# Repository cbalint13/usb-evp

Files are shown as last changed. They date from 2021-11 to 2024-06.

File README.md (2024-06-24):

# usb-evp
**USB Event Packet** protocol (LoRA) Stick

Original project dating back @ 2018 [CircuitMaker USB-EVP-LoRa](https://workspace.circuitmaker.com/Projects/Details/Cristian-Balint/USB-EVP-LoRa)

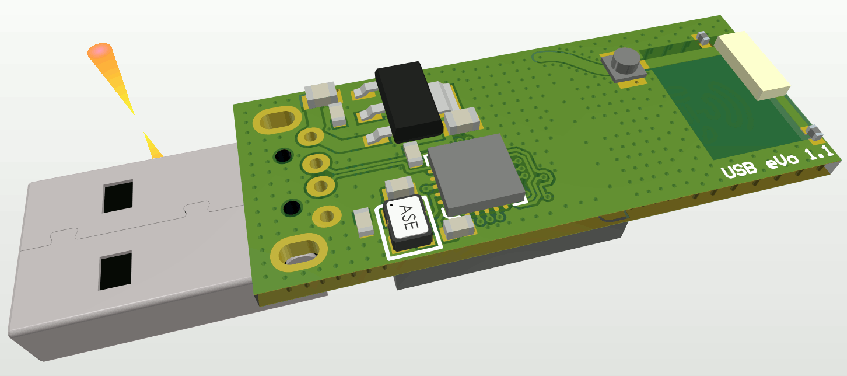
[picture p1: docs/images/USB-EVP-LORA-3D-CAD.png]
OVERVIEW-3D-CAD


## Description

USB stick for **Event Packet** (over LoRa) with integrated antenna on ISM 868/915 bands.

Exposes a generic USB HID interface by MCP2210 directly enabling OS & driver agnostic access from userland.

It have a minimal BOM (bill of materials).
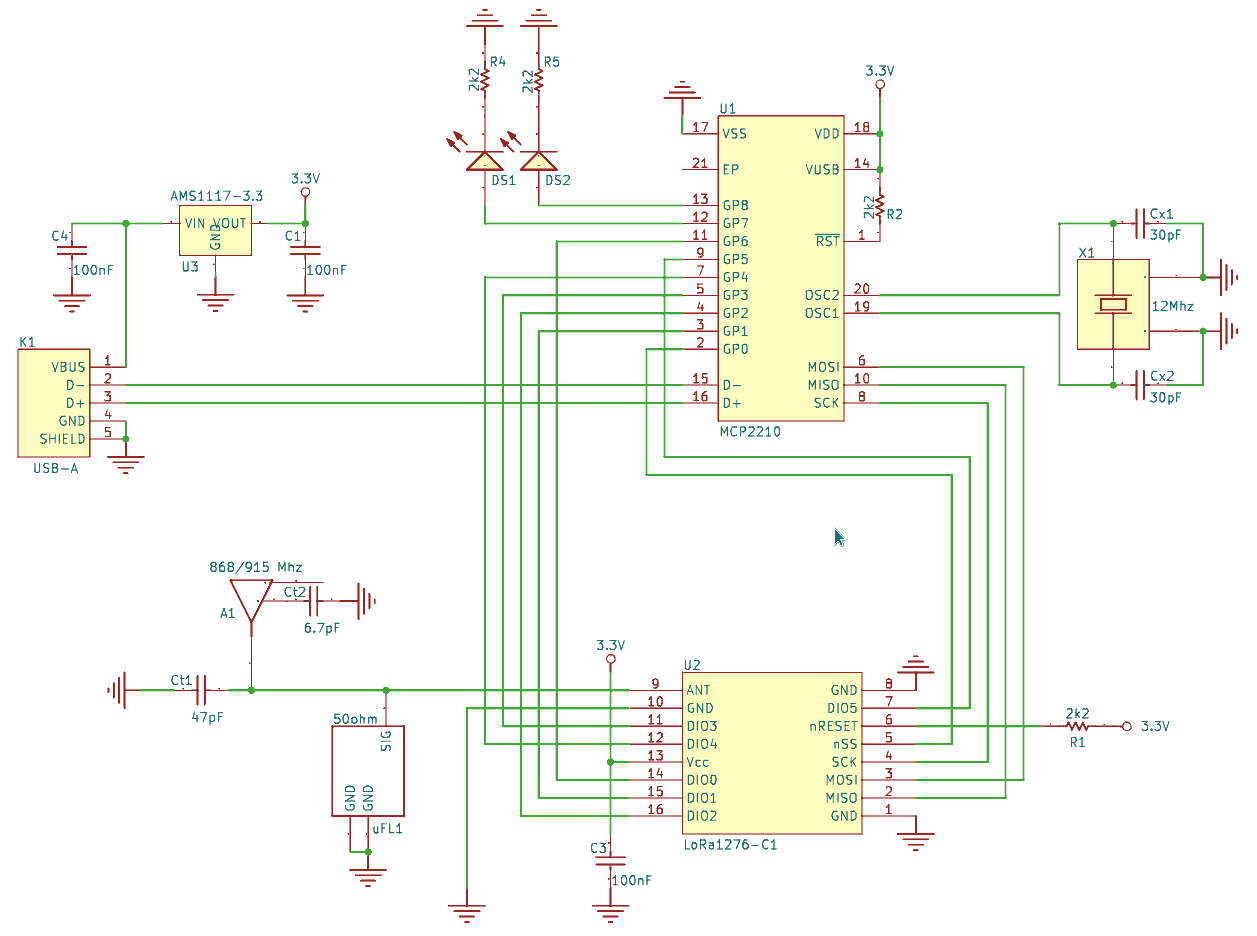
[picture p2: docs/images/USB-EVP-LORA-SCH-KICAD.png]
OVERVIEW-3D-SCHD


## Specs:

* **Smallest LoRa stick** on the market by 1.6 x 4 cm
* Uses FCC and CE **certified** 100mW NiceRF module
* Own **ceramic micro-antenna** (VNA proved RF) for ISM band
* **OS agnostic**, opensource USB stack for windows, linux, android etc
* **C / C++** frontend with various examples
* May support **LPWAN networking** (IPv6 over 802.15.4 mac layer), with third party kernel module

Can be used in any USB port realying packets over the air.

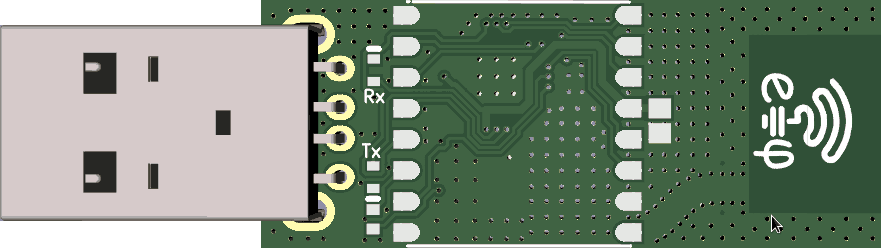
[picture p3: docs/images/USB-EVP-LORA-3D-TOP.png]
OVERVIEW-3D-TOP

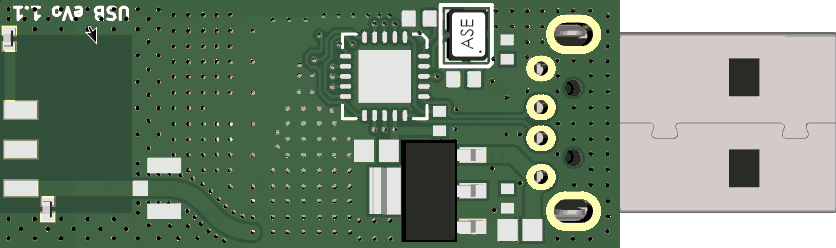
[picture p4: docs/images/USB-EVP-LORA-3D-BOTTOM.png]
OVERVIEW-3D-BOTTOM


## EU ISM band usage 
* [LoRa 868Mhz bands diagram](docs/legal)

## Design files
* See the [design files](hardware) available for Altium ®, CircuitMaker ®, KiCAD and Gerber format.
* Check [schematic](hardware/USB-eVo_v1.1.pdf) available as quick readable format.
* There is also an CircuitMaker ® [online version](https://circuitmaker.com/Projects/Details/Cristian-Balint/USB-EVP-LoRa) available.

## Software support
* See [software](software) section for configuration and support.

    ```
    $ ./bin/lora-receive /dev/hidraw4 
    LoRa RX count #1 frame length = 14 rssi = -61 dB snr = 8 dB
    0x00000000 20 6C 6F 72 61 20 6D 65  73 73 61 67 65 00 |  A lora message.
    ```

## Board images
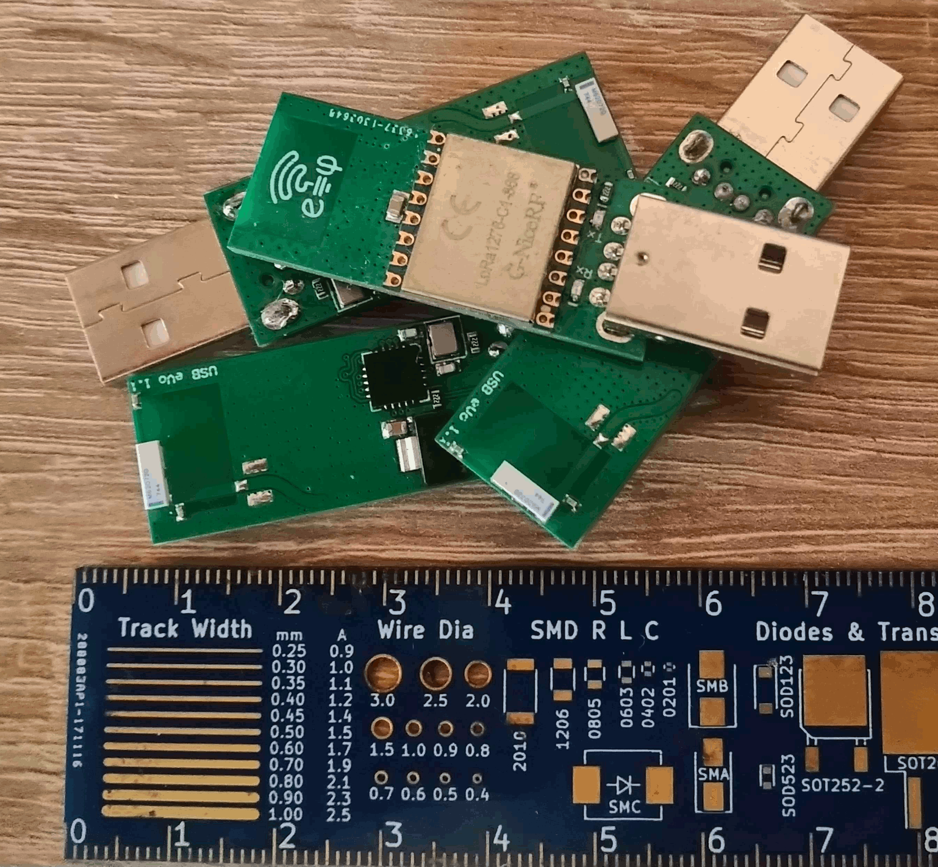
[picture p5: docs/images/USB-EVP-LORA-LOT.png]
OVERVIEW-TOP


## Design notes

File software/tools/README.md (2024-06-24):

# USB stick library stack

You can compile all tools using the provided ```make.sh```.

---

## Applications

 * Use ```scan.sh``` to fetch the exact device path:

    ```
    $ ./scan.sh
    /dev/hidraw0 Lite-On Technology Corp. Lenovo Low Profile USB Keyboard
    /dev/hidraw1 Lite-On Technology Corp. Lenovo Low Profile USB Keyboard
    /dev/hidraw2 ITE Tech. Inc. ITE Device
    /dev/hidraw3 Designer Mouse
    /dev/hidraw4 EventPacket [eVo] USB Stick v1.2
    ```

 * Chipset (SX127x) revision check:

    ```
    $ ./bin/check-version /dev/hidraw4
    SX127X chip version: 0x12
    ```

 * Random number generator based on wideband RSSI measurement:

    ```
    $ ./bin/sx127x-random /dev/hidraw4
    Found SX127X chip version: 12
    253
    186
    97
    216
    157
    ...
    ```

 * LoRa receive example:

    ```
    $ ./bin/lora-receive /dev/hidraw4 
    LoRa RX count #1 frame length = 14 rssi = -61 dB snr = 8 dB
    0x00000000 20 6C 6F 72 61 20 6D 65  73 73 61 67 65 00 |  A lora message.
    ```

 * LoRa sending example:

    ```
    $ ./bin/lora-send /dev/hidraw4
    LoRa sent message
    ```

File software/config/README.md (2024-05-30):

# LoRa USB stick initial configuration

* Please check and compile the [mcp2210-tool](https://github.com/lkundrak/mcp2210)
* Use the ```evp-lora-stick-hwcfg.sh``` script to initialize the USB stick NVRAM settings

---

The ```dmesg``` output summary:

```
$ dmesg
...
[296427.566309] usb 1-6: new full-speed USB device number 7 using xhci_hcd
[296427.695951] usb 1-6: New USB device found, idVendor=04d8, idProduct=00de, bcdDevice= 0.02
[296427.695968] usb 1-6: New USB device strings: Mfr=1, Product=2, SerialNumber=3
[296427.695975] usb 1-6: Product: [eVo] USB Stick v1.2
[296427.695981] usb 1-6: Manufacturer: EventPacket
[296427.695986] usb 1-6: SerialNumber: 0000818649
[296427.700092] hid-generic 0003:04D8:00DE.0005: hiddev97,hidraw4: USB HID v1.11 Device [EventPacket [eVo] USB Stick v1.2] on usb-0000:00:14.0-6/input0
...
```

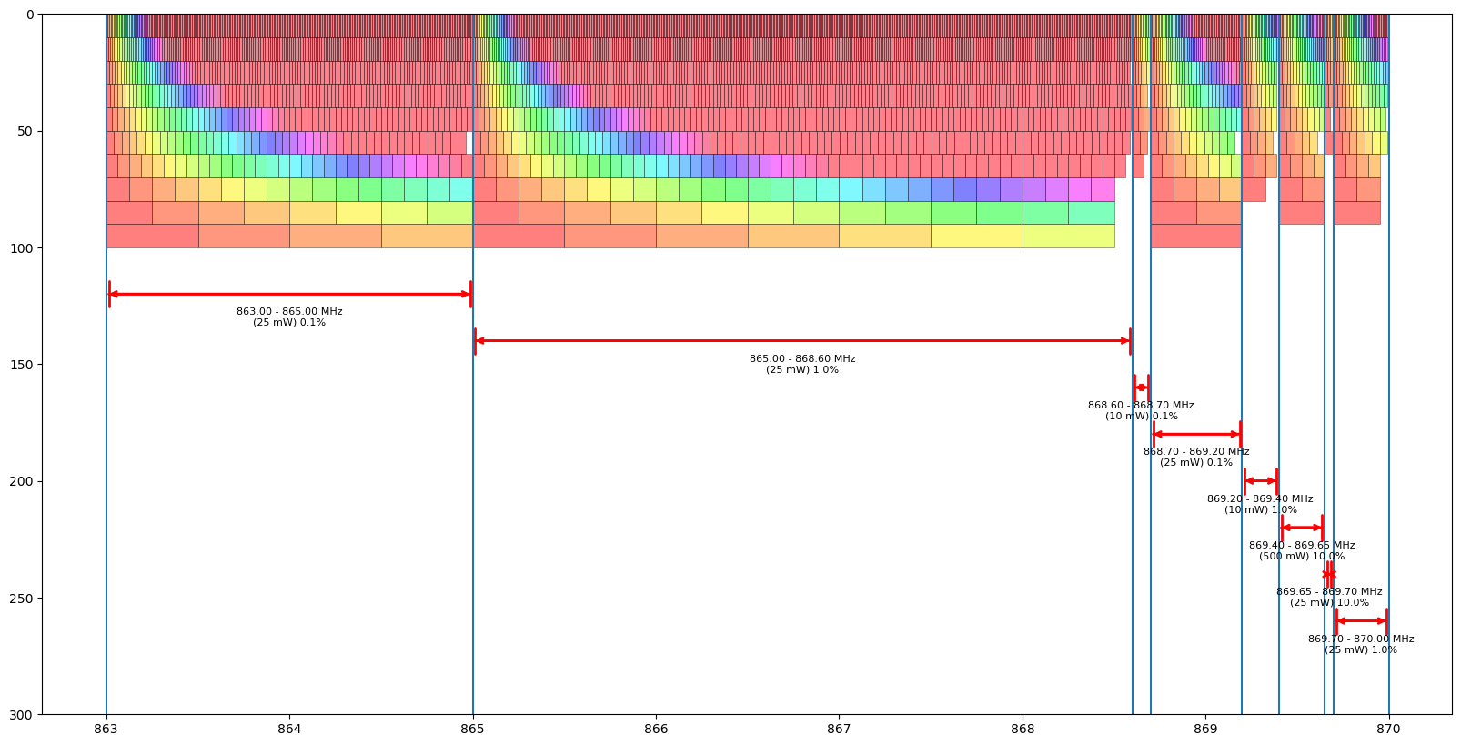
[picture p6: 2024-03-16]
docs/legal/lora-channels-EU.png

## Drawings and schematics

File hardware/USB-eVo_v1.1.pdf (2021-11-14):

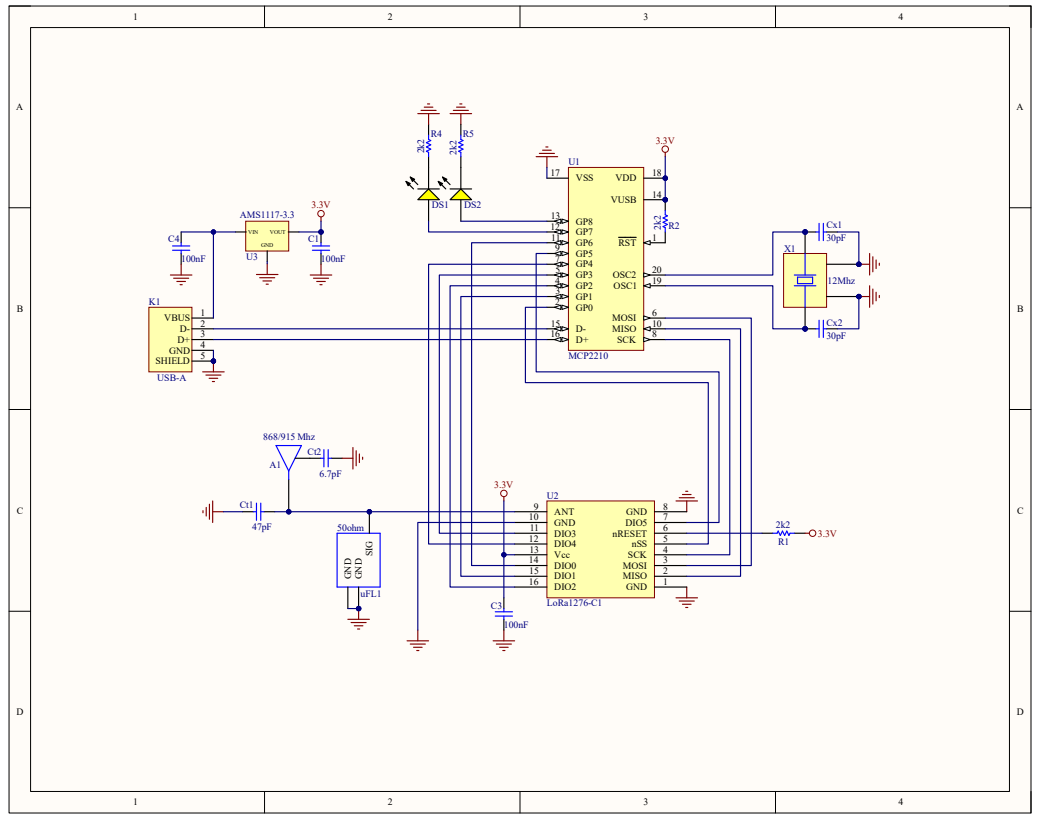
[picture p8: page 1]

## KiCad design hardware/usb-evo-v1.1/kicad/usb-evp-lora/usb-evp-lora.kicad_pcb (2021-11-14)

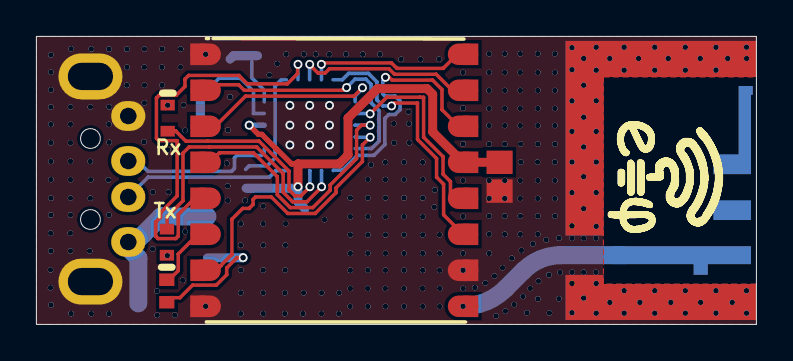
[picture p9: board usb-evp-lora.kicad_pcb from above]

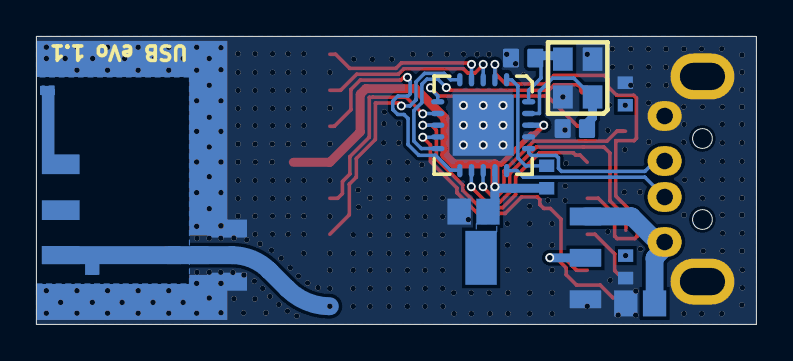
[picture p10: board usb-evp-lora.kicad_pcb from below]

Board: 2 copper layers, 40.0 x 16.0 mm, 20 parts (14 on the bottom side), 25 nets.

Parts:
A1: 868/915 Mhz; M620720
C1, C3, C4: 100nF; CAPC2013X88X50NL20T25
Ct1: 47pF; SMD0402
Ct2: 6.7pF; SMD0402
Cx1, Cx2: 30pF; PCB-EK4STCKT8HTL49C36KEC-1
DS1, DS2: LED-0603; VISH-TLMX1100-2_V
K1: USB-A; USB-A-H
R1, R2, R4, R5: 2k2; RESC1608X55X30LL15T15
U1: MCP2210; QFN-MQ20_N
U2: LoRa1276-C1; PCB-A2VA5FQQIKHNLZOD9I25-1
U3: AMS1117-3.3; MP04A_N
X1: 12Mhz; PCB-O7TDNPTWBJGDFBSKC48Q-1
uFL1: 50ohm; HRS-U.FL-R-SMT_V

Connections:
3.3V: C1.2, C3.2, R1.1, R2.1, U1.14, U1.18, U2.13, U3.2
GND: A1.GND, C1.1, C3.1, C4.1, Ct1.2, Ct2.1, Cx1.1, Cx2.1, K1.4, K1.5, R4.2, R5.2, U1.17, U1.21, U2.1, U2.8, U2.10, U3.1, X1.2, X1.4, uFL1.1, uFL1.2
NetA1_1: A1.1, Ct1.1, U2.9, uFL1.3
NetA1_2: A1.2, Ct2.2
NetC4_2: C4.2, K1.1, U3.3
NetCx1_2: Cx1.2, U1.20, X1.3
NetCx2_2: Cx2.2, U1.19, X1.1
NetDS1_1: DS1.1, U1.12
NetDS1_2: DS1.2, R4.1
NetDS2_1: DS2.1, U1.13
NetDS2_2: DS2.2, R5.1
NetK1_2: K1.2, U1.15
NetK1_3: K1.3, U1.16
NetR1_2: R1.2, U2.6
NetR2_2: R2.2, U1.1
NetU1_2: U1.2, U2.5
NetU1_3: U1.3, U2.15
NetU1_4: U1.4, U2.16
NetU1_5: U1.5, U2.11
NetU1_6: U1.6, U2.3
NetU1_7: U1.7, U2.12
NetU1_8: U1.8, U2.4
NetU1_9: U1.9, U2.7
NetU1_10: U1.10, U2.2
NetU1_11: U1.11, U2.14

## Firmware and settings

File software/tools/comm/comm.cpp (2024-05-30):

/*
 * Copyright (C) 2019  Balint Cristian <crisitan dot balint at gmail dot com>
 *
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
 * You should have received a copy of the GNU General Public License
 * along with this program.  If not, see <http://www.gnu.org/licenses/>.
 */

#include <fcntl.h>
#include <stdio.h>
#include <unistd.h>
#include <random>

#include "drvs/spi.h"
#include "devs/lora.h"
#include "devs/mcp2210.h"

#include "comm/comm.hpp"

extern uint8_t _headerMode;
extern uint8_t _payloadLength;

LORA::LORA(char hiddevice[],
           uint8_t headerMode = LR_EXPLICIT_HEADER_MODE,
           int8_t txpower = 2,
           uint32_t freq = 868000000,
           uint8_t bandwidth = LR_BW_500k,
           uint8_t codingrate4 = LR_CODINGRATE_2,
           uint8_t spreadfactor = LR_SPREADING_FACTOR_7,
           uint8_t crcpayload = LR_PAYLOAD_CRC_ON,
           uint8_t syncword = 13,
           uint8_t preamblelen = 8,
           uint8_t maxlength = 250)
{
    // set global header mode
    _headerMode = headerMode;
    _payloadLength = maxlength;

    // open USBRAW device
    _fd = open(hiddevice, O_RDWR);

    // reset lora
    lora_reset();
    // settings mode require sleep
    lora_enterSleepMode();
    // set power dBm
    // -3..1, 2..17, 20
    lora_setTxPower(txpower);
    // close ocp
    SPIWriteReg(LR_RegOcp, LR_OCPON_ON | 0x0B);
    // enable LNA
    SPIWriteReg(LR_RegLna, LR_LNAGAIN_G1
                         | LR_LNABOOSTHF_1);
    // bandwidth
    // coding rate
    // spreading factor
    // implict header mode
    lora_setRFparams(freq,
                     bandwidth,
                     codingrate4,
                     spreadfactor,
                     crcpayload);

    // Low datarate schedule
    //SPIWriteReg(LR_RegModemConfig3, LR_LOW_DATARATE_OPTIMIZE);
    // Sync Word 0x13
    SPIWriteReg(LR_RegSyncWord, syncword);
    // max rx time out
    lora_setRxTimeOut(0x05);
    // preamble 12+4.25 bytes
    lora_setPreambleLen(preamblelen);
    // max payload length (250 bytes)
    SPIWriteReg(LR_RegMaxPayloadLength, maxlength);
    lora_disableInvertIQ();

    // switch states
    lora_enterStbyMode();
    lora_enterSleepMode();

    // set state
    LORA::loraState = LR_Mode_SLEEP;
}

LORA::~LORA(void)
{
    close(_fd);
}

uint8_t LORA::rx_packet(uint8_t *msg_buf)
{
    uint8_t rx_len = 0;

    led(LED_TX, LED_OFF);
    led(LED_RX, LED_OFF);

    // no rx mode reinit
    if (LORA::loraState != LR_Mode_RXCONTINUOUS)
    {
        lora_rxInit(LR_Mode_RXCONTINUOUS, 0);
        LORA::loraState = LR_Mode_RXCONTINUOUS;
    }

    // soft poll IRQ
    while (true)
    {
        // check IRQ status
        uint8_t flag = SPIReadReg(LR_RegIrqFlags);

        // rx CRC error
        if(flag & LR_RXPCRCERROR_MASK)
        {
            printf("LoRa RX CRC error.\n");
            lora_clrInterrupt();
        }
        // rx TIMEOUT error
        if(flag & LR_RXTIMEOUT_MASK)
        {
            printf("LoRa RX TIMEOUT error.\n");
            lora_clrInterrupt();
        }
        // rx DONE
        if(flag == LR_RXDONE_MASK)
        {
            led(LED_RX, LED_ON);
            // fetch len & data
            rx_len = lora_rxPacket(msg_buf);
            // clear IRQ
            lora_clrInterrupt();

            break;
        }
        // 10ms wait
        usleep(50000);
    }

    led(LED_RX, LED_OFF);
    return rx_len;
}

void LORA::tx_packet(uint8_t *msg_buf, const uint8_t msg_len)
{
    // send packet
    led(LED_TX, LED_ON);
    lora_txPacket(msg_buf, msg_len, LORA_TX_WAITACK);
    LORA::loraState = LR_Mode_SLEEP;
    led(LED_TX, LED_OFF);
}

int16_t LORA::rssi(void)
{
   uint32_t freq = lora_getFrequency();
   uint8_t offset = ((freq < RF_MID_BAND_THRESHOLD) \
                  ? RSSI_OFFSET_LF_PORT : RSSI_OFFSET_HF_PORT);
   // read rssi of last packet received
   int16_t rssi = (int16_t)lora_readRSSI(LORA_RSSI_LAST) - offset;
   return rssi;
}

int8_t LORA::snr(void)
{
   return (lora_readSNR() / 4);
}

void LORA::led(uint8_t rx_tx, bool value)
{
    if ((rx_tx < 7) || (rx_tx > 8)) return;
    mcp2210_packet packet = {0, };

    mcp2210_command(_fd, packet, MCP2210_GPIO_DIR_GET);
    mcp2210_chip_set_default_direction(packet, rx_tx, 1);
    mcp2210_command(_fd, packet, MCP2210_GPIO_DIR_SET);

    mcp2210_command(_fd, packet, MCP2210_GPIO_VAL_GET);
    mcp2210_gpio_set_pin(packet, rx_tx, value);
    mcp2210_command(_fd, packet, MCP2210_GPIO_VAL_SET);
}

uint32_t LORA::rx_count(void)
{
    mcp2210_packet packet = {0, };
    return mcp2210_gp6_count_get(_fd, packet, true /*no reset*/);
}

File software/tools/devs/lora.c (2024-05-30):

/*
 * Copyright (C) 2019  Balint Cristian <crisitan dot balint at gmail dot com>
 *
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
 * You should have received a copy of the GNU General Public License
 * along with this program.  If not, see <http://www.gnu.org/licenses/>.
 */

#include <stdio.h>

#include <stdint.h>
#include <unistd.h>

#include "drvs/spi.h"
#include "devs/lora.h"


uint8_t _headerMode;
uint8_t _payloadLength;

void lora_init(uint8_t headerMode)
{
    // reset lora
    lora_reset();
}

void lora_reset(void)
{
    /* not implemented */
}

void lora_config(uint8_t headerMode)
{
    // set global header mode
    _headerMode = headerMode;

    // settings mode require sleep
    lora_enterSleepMode();

    // set power dBm
    // -3..1, 2..17, 20
    lora_setTxPower(2);

    // close ocp
    SPIWriteReg(LR_RegOcp, LR_OCPON_ON | 0x0B);

    // enable LNA
    SPIWriteReg(LR_RegLna, LR_LNAGAIN_G1
                         | LR_LNABOOSTHF_1);
    // bandwidth
    // coding rate
    // spreading factor
    // implict header mode
    lora_setRFparams(868000000,
                     LR_BW_500k,
                     LR_CODINGRATE_2,
                     LR_SPREADING_FACTOR_7,
                     LR_PAYLOAD_CRC_ON);

    // Sync Word 0x13
    SPIWriteReg(LR_RegSyncWord, 0x13);

    // max rx time out
    lora_setRxTimeOut(0x05);

    // preamble 12+4.25 bytes
    lora_setPreambleLen(13);

    // max payload length (250 bytes)
    SPIWriteReg(LR_RegMaxPayloadLength, 250);

    // switch states
    lora_enterStbyMode();
    lora_enterSleepMode();
}

void lora_setFrequency(uint32_t freq)
{
    uint8_t reg[3];
    /*
     * Frf(23:0)=frequency/(XOSC/2^19)
     */
    uint64_t frf = ((uint64_t)freq << 19) / LORA_XOSC;

    reg[0] = (uint8_t)(frf >> 16);
    reg[1] = (uint8_t)(frf >>  8);
    reg[2] = (uint8_t)(frf >>  0);

    SPIWriteReg(LR_RegFrMsb, reg[0]);
    SPIWriteReg(LR_RegFrMid, reg[1]);
    SPIWriteReg(LR_RegFrLsb, reg[2]);
}

uint32_t lora_setRFerrata(uint32_t freq, uint8_t BW)
{
    // only for silicon version 1b
    if (SPIReadReg(LR_RegVERSION) != 0x12)
        return freq;

    // sensitivity
    // for 500kHz bandwidth
    // see SX1276/77/78 Errata
    // section 2.1 for details
    SPIWriteReg(LR_RegHighBwOptimize1, 0x03);
    if (BW == LR_BW_500k)
    {
        if ((freq <= 525000000)
         && (freq >= 410000000))
        {
            SPIWriteReg(LR_RegHighBwOptimize1, 0x02);
            SPIWriteReg(LR_RegHighBwOptimize2, 0x7F);
        }
        if ((freq <= 1020000000)
         && (freq >=  862000000))
        {
            SPIWriteReg(LR_RegHighBwOptimize1, 0x02);
            SPIWriteReg(LR_RegHighBwOptimize2, 0x64);
        }
    }

    // receiver
    // spurious response
    // see SX1276/77/78 Errata
    // section 2.3 for details
    uint8_t val = SPIReadReg(LR_RegDetectOptimize);
    if (BW == LR_BW_500k)
        SPIWriteReg(LR_RegDetectOptimize, val |  (1 << 7));
    else
        SPIWriteReg(LR_RegDetectOptimize, val & ~(1 << 7));

    switch (BW)
    {
        case LR_BW_7p8k:
            SPIWriteReg(LR_RegIfFreq1, 0x48);
            SPIWriteReg(LR_RegIfFreq2, 0x00);
            freq += 7800;
            break;
        case LR_BW_10p4k:
            SPIWriteReg(LR_RegIfFreq1, 0x44);
            SPIWriteReg(LR_RegIfFreq2, 0x00);
            freq += 10400;
            break;
        case LR_BW_15p6k:
            SPIWriteReg(LR_RegIfFreq1, 0x44);
            SPIWriteReg(LR_RegIfFreq2, 0x00);
            freq += 15600;
            break;
        case LR_BW_20p8k:
            SPIWriteReg(LR_RegIfFreq1, 0x44);
            SPIWriteReg(LR_RegIfFreq2, 0x00);
            freq += 20800;
            break;
        case LR_BW_31p25k:
            SPIWriteReg(LR_RegIfFreq1, 0x44);
            SPIWriteReg(LR_RegIfFreq2, 0x00);
            freq += 31250;
            break;
        case LR_BW_41p7k:
            SPIWriteReg(LR_RegIfFreq1, 0x44);
            SPIWriteReg(LR_RegIfFreq2, 0x00);
            freq += 41700;
            break;
        case LR_BW_62p5k:
            SPIWriteReg(LR_RegIfFreq1, 0x40);
            SPIWriteReg(LR_RegIfFreq2, 0x00);
            break;
        case LR_BW_125k:
            SPIWriteReg(LR_RegIfFreq1, 0x40);
            SPIWriteReg(LR_RegIfFreq2, 0x00);
            break;
        case LR_BW_250k:
            SPIWriteReg(LR_RegIfFreq1, 0x40);
            SPIWriteReg(LR_RegIfFreq2, 0x00);
            break;
    }
    return freq;
}

void lora_setRFparams(uint32_t freq, uint8_t BW, uint8_t CR, uint8_t SF, uint8_t payloadCRC)
{
    uint8_t temp;

    temp = SPIReadReg(LR_RegModemConfig2);
    temp = temp & 0x03;

    // with SF = 6 selected
    // only implicit header mode is available
    if(SF == LR_SPREADING_FACTOR_6)
    {
        _headerMode = LR_IMPLICIT_HEADER_MODE;
        SPIWriteReg(LR_RegModemConfig1, BW | CR | _headerMode);
        SPIWriteReg(LR_RegModemConfig2, SF| payloadCRC| temp);

        // according to datasheet
        temp = SPIReadReg(LR_RegDetectOptimize);

        temp &= 0xF8;
        temp |= 0x05;

        SPIWriteReg(LR_RegDetectOptimize,     temp);
        SPIWriteReg(LR_RegDetectionThreshold, 0x0C);
    }
    else
    {
        SPIWriteReg(LR_RegModemConfig1, BW | CR | _headerMode );
        SPIWriteReg(LR_RegModemConfig2, SF | payloadCRC | temp);
    }

    // Low Data Rate optimizaition
    lora_setLdoFlag();

    // set erratas
    freq = lora_setRFerrata(freq, BW);

    // set frequency
    lora_setFrequency(freq);

}

void lora_setPreambleLen(uint16_t length)
{
    // the actual preamble len is length+4.25
    SPIWriteReg(LR_RegPreambleMsb, length   >> 8);
    SPIWriteReg(LR_RegPreambleLsb, length & 0xFF);
}

void lora_setHeaderMode(uint8_t mode)
{
    _headerMode = mode;

    uint8_t temp;
    // avoid overload the other setting
    temp = SPIReadReg(LR_RegModemConfig1);
    temp = temp & 0xFE;

    SPIWriteReg(LR_RegModemConfig1, temp | mode);
}

// in implict header mode, the payload length is fixed
// len thus need to set payload length first in this mode
void lora_setPayloadLength(uint8_t len)
{
    _payloadLength = len;
    SPIWriteReg(LR_RegPayloadLength, len);
}
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

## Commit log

2021-11-14 Publish hardware.
    [USB-eVo.PcbDoc, USB-eVo.PcbLib, USB-eVo.PrjPcb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]
2021-12-21 Replace preview SCH with KiCAD one.

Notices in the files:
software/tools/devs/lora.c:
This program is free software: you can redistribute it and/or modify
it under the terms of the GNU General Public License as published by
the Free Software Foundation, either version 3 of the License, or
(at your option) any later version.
